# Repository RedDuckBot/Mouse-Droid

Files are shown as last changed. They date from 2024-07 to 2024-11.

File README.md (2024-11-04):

# Mouse_Droid
A differential drive mouse droid, from the Star Wars universe, that was design for entertaining people at a house party. The droid is equiped with a revolving disco ball and can make actual mouse droid sounds heard from the movies. It is manually operated using an Xbox 360 wired controller. Overall, the operations of droid involves a raspberry pi 3B+, utilizing Ubuntu Server 22.04, and the running software application is built on the middleware ROS2 Humble. Majority of the parts are 3D printed and the droid consists of many other basic electronic components. Using a PID controller the droid is able to do a 180 degree or complete rotation.    

<p align='center'>
    
</p>
<p align='center'>
    
</p>

## 🗃️ Package Overview
- [`droid_server_commands`](./droid_setup/ros2_ws/src/droid_server_commands/) : Contains action server nodes for handling controller input
- [`droid_controller`](./remote_setup/ros2_ws/src/droid_controller/) : Contains action client node that casts the inputs for the Xbox 360 controller
- [`droid_interfaces`](./remote_setup/ros2_ws/src/droid_interfaces/) : Contains the ROS2 actions and messages used in this project representing the data for Xbox 360 controller

## 🧰 Hardware

<p align='center'>
    
</p>

| | Electronic Components |
| --| --|
|1| Raspberry Pi 3B+ |
|2| Lexar 128 GB SD Card |
|3| Sound Board DY-HV20T |
|4| 4 Ohm 5W Audio Speaker |
|5| Motor Controller L298N  |
|6| [4 x DC-12V-200RPM Motors](https://ca.robotshop.com/products/lynxmotion-12vdc-200rpm-078kg-cm-ghm-16-w-rear-shaft?variant=42411388829847)|
|7| DC 5V Stepper Motor 28BYJ-48 |
|8| ULN2003 Step Driver Board |
|9| [12mm (Outside Diameter) Slip Ring](https://www.amazon.ca/dp/B07H2SRMXP?psc=1&ref=ppx_yo2ov_dt_b_product_details) |
|10| [Mini USB Disco Ball with 62mm Diameter](https://www.amazon.ca/dp/B0BK6Z3LYH?ref=ppx_yo2ov_dt_b_product_details&th=1) |
|11| 12V, 3800mAh LIPO Battery |
|12| 5V, 26000mAh Battery Bank |

### 3D Printed Parts

The parts for the droids body were taken from a maker on Thingiverse, [Null_Hypothesis](https://www.thingiverse.com/null_hypothesis/designs). Here's the link to his project https://www.thingiverse.com/thing:4229599.
From his project only the following parts are needed, given that the design needed to be hacked to work for a diff drive droid:
- 2 x Chassis_Rear_V4.stl
- Top_FrontV4.stl
- Top_RearV4.stl
- Top_rightV4.stl
- Top_RoofV4.stl
- TopLeftV4.stl
- 2 x Mouse_Droid_Side_Circuit_Board_Rescaled.stl   
- 2 x MSE_base 6to10.stl
- 2 x MSE_Lower_Portion6to10.stl
- 2 x MSE_Upper_Portion 6to10.stl
- 4 x Front_Tire.stl

The parts mentioned above and custom parts made for this project are in the 3D_print_files directory.
Portions of the chassis where the wheels go were cut out for placing the custom motor mounts, and a 64mm hole was cut out from the droid's roof for dico ball placement. Moreover, the custom disco platforms, made to hold electronic and mechanical components for operating it, are suspended bellow the droid's roof using hex brass standoffs. [`Images`](./docs/images/) were taken to show assembeled components.  

## Circuit Diagrams 
### Disco Ball Circuit
<p align="center">
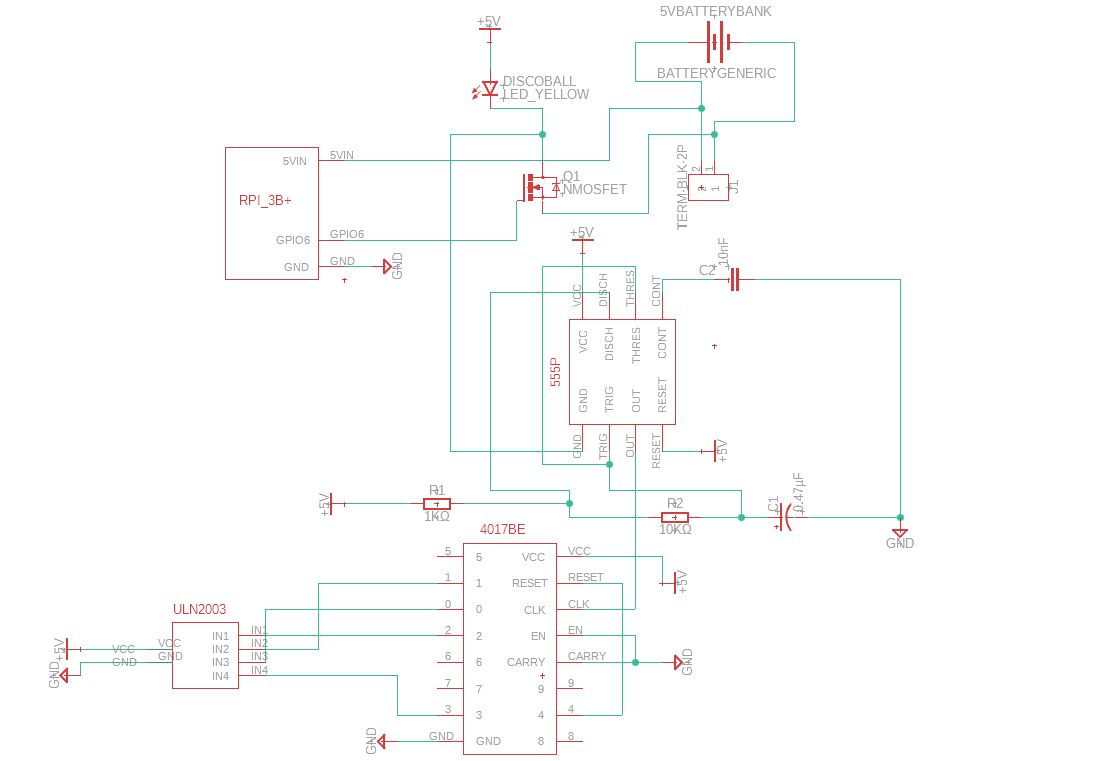
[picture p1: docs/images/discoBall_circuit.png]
Disco Ball Circuit
  
</p>
Rotational control for the disco ball was done using a custom circuit, as shown above, involving a 555 timer, 4017 Decade counter, few resistors, capacitors, and an N-mosfet. This circuit generates steps for the stepper motor and was controlled off a pin from the Raspberry Pi that connected to the mosfet; operation can easily be achieved by directly connecting the Pi's pins to the ULN2003 Step board, instead of making and using the custom circuit.
Note: since the disco ball uses a USB connection a portion of the metal connector was cut out to expose the Vin and GND pins, which were soldered to the spin wires of the slip ring with the out wires connecting to the mosfet.

### Sound Board, Motor Controller, and IMU Circuit
<p align="center">
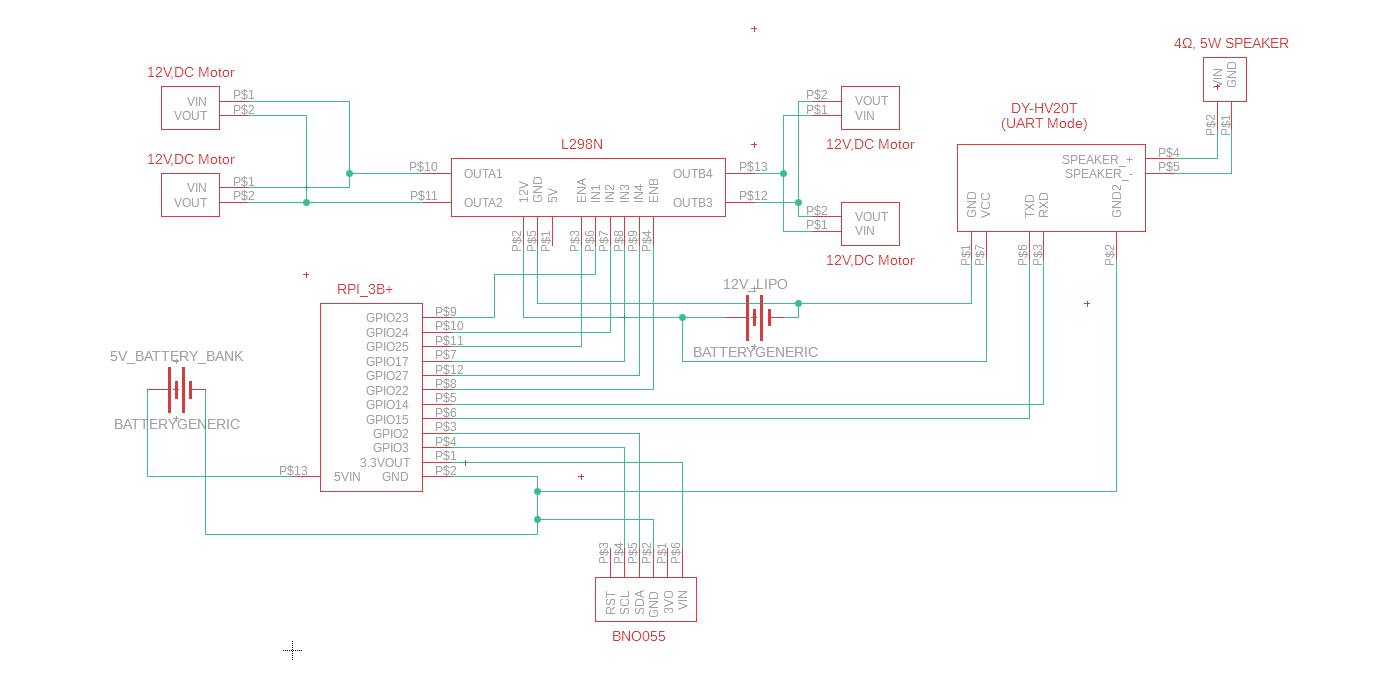
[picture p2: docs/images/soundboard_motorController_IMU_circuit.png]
Sound Board, Motor Controller, and IMU Circuit
  
</p>
In the above diagram, two power sources are utilized: 3s LIPO battery for powering the sound board and motors, and 5V battery bank for the Raspberry PI and disco circuit.

## Setup for operating the Droid 

The remote computer for controlling the droid does not need to install ROS2 Humble since in this setup a Docker container is utilized (for easy setup), but on the Raspberry PI this needs to be installed.
Copy the directory [`remote_setup`](./remote_setup/) onto the remote machine, and [`droid_setup`](./droid_setup/) onto the Raspberry PI.

### Remote Setup
For network communication, this project utilizes Eclipse Cyclone DDS, so before building and running the Docker container, add both the PI's and remote computer's IP addresses to the [`cyclon file`](./remote_setup/cyclonedds.xml). Moreover, this document provides comments for where to place these addresses. 

After modifying the cyclon file, build & run the container:

```
Scripts/build.bash
```
Next, run the container but make sure the Xbox 360 controller is connected.

```
Scripts/run.bash
```

Finally, before running the controller node, the ROS2 packages for this setup need to be compiled and installed.

```
cd ws/
colcon build
source install/setup.bash
ros2 run droid_controller controller
```
Expect similar output, after running the controller node: [INFO] [1720638165.505265926] [controller]: Xbox controller node initialized.

### Droid Setup
Make sure the library [pigpio](https://abyz.me.uk/rpi/pigpio/) is installed on the Raspberry PI.
Given permission issues encountered when trying to run the droid server node on the PI, the work around solution is running this node while logged in as the root user. 

Before compiling and installing the ROS2 packages for this setup, run the following commands:
```
source /opt/ros/humble/setup.bash
export RMW_IMPLEMENTATION=rmw_cyclonedds_cpp
export ROS_DOMAIN_ID=0
export CYCLONEDDS_URI= ./droid_setup/cyclonedds.xml #Enter the full location of the cyclon DDS file
```

Then, as done in the remote setup, add the PI's and remote computer's IP addresses to the cyclon file.
Next, while in the the directory ./droid_setup/ros2_ws, compile the droids ROS2 packages:

```
colcon build
source install/setup.bash
```

Finally, run the droid server node which takes commands from the controller node:
```
ros2 run droid_server_commands droid_server
```

Expect similar output, after running this node: 
```
[INFO] [1720639837.026257729] [Droid_Server]: IMU Module Ready
[INFO] [1720639837.164474318] [Droid_Server]: Sound Module Ready
[INFO] [1720639837.164727443] [Droid_Server]: Droid servers started
```

### Xbox 360 Controller Commands
- Left Joy-stick ---> operates left side motors
- Right Joy-stick ---> operates right side motors
- Back button ---> Droid performs an automatic 180 deg rotation
- Mode button (between back & start buttons) ---> Droid performs an automatic 360 deg rotation
- X, Y, B, A buttons ---> Perform droid sounds
- Start button ---> toggles disco ball on and off

The droid sounds are in [`resources`](./resources/) and can be installed to an SD for the sound board. 

## Acknowledgements
- [IMU Module](https://github.com/CVino/RPi_BNO055)
- [Motor Wrapper](https://github.com/buildrobotsbetter/rpi4b_gpio-example)
- [Sound Module](https://github.com/SnijderC/dyplayer)

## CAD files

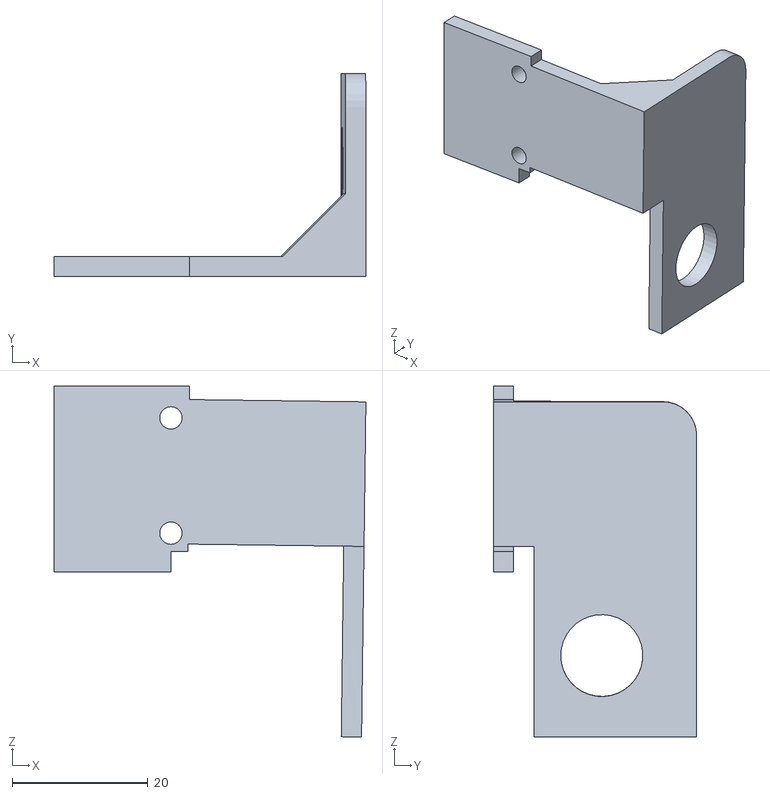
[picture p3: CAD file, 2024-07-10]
3D_print_files/custom_parts/left_side_motor_bracket.stl
46.0 x 30.0 x 51.8

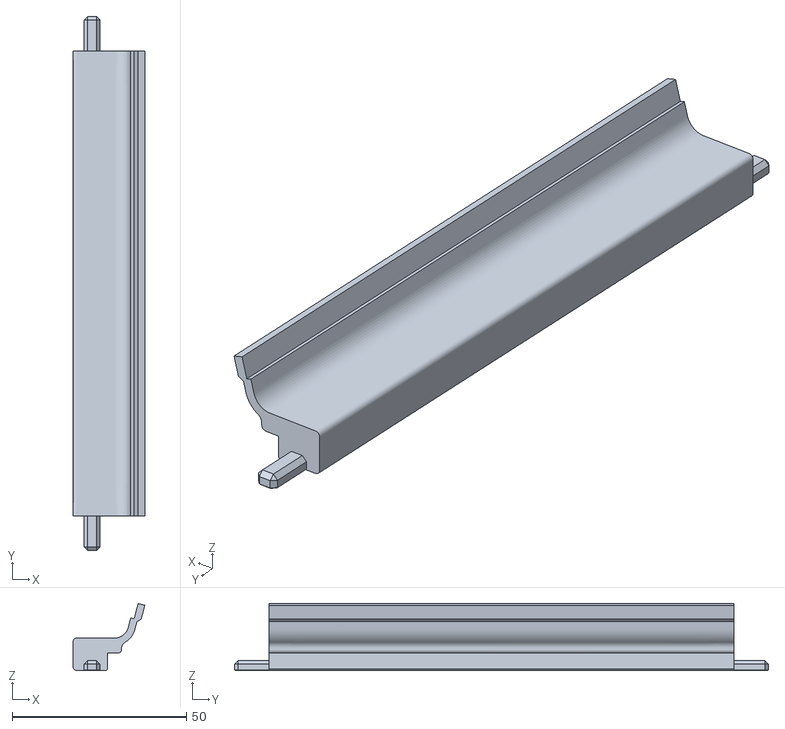
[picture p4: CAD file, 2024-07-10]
3D_print_files/original_parts/TopLeftV4.stl
20.6 x 153.0 x 19.2

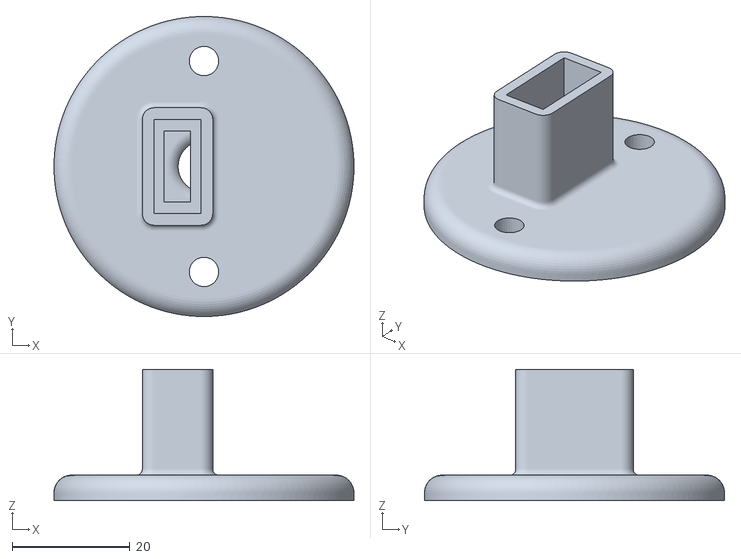
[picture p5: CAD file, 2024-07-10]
3D_print_files/custom_parts/disco_holder.stl
51.1 x 51.1 x 22.4

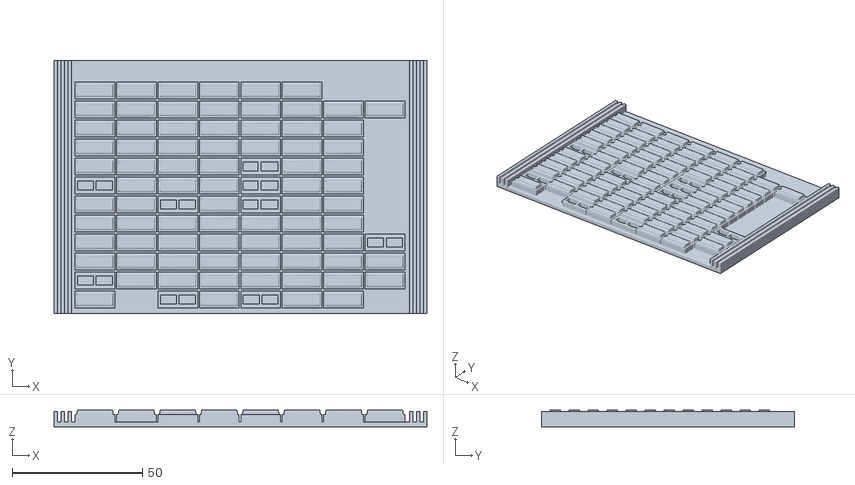
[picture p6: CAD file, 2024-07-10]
3D_print_files/original_parts/Mouse_Droid_Side_Circuit_Board_Rescaled.stl
143.0 x 97.2 x 6.37

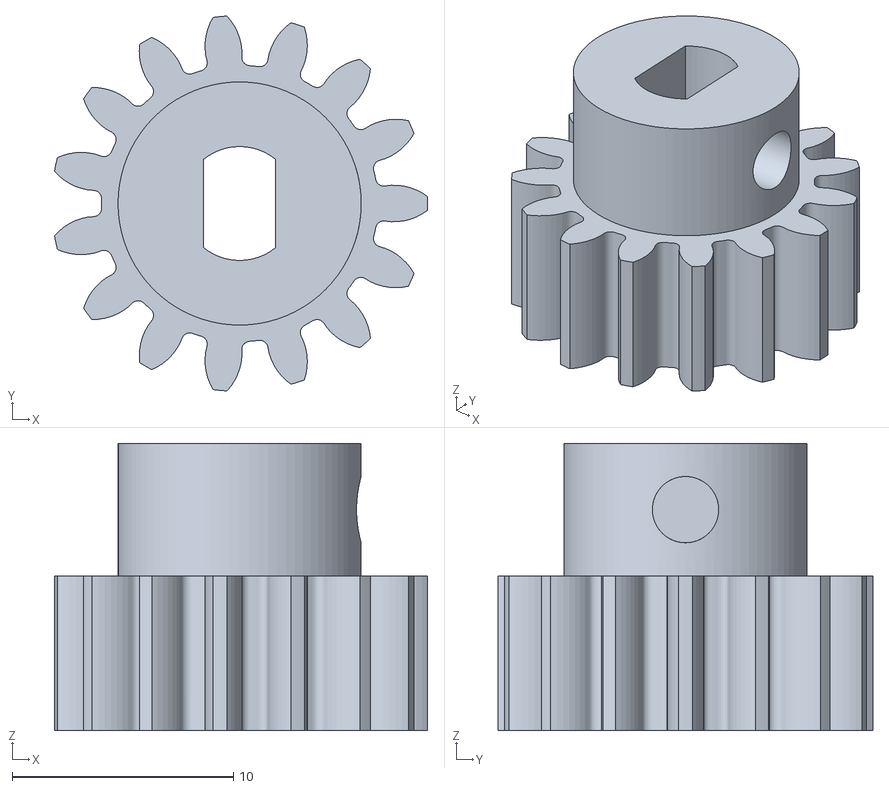
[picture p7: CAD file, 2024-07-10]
3D_print_files/custom_parts/stepper_driven_gear.stl
16.9 x 17.0 x 13.0

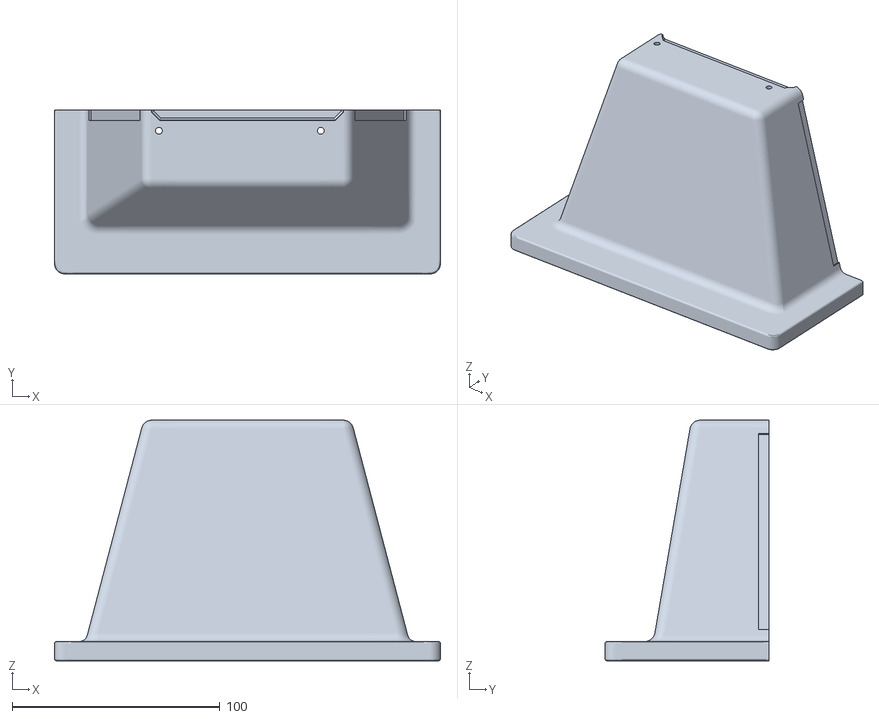
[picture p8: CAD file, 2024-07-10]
3D_print_files/original_parts/Top_RearV4.stl
186.0 x 79.0 x 115.9

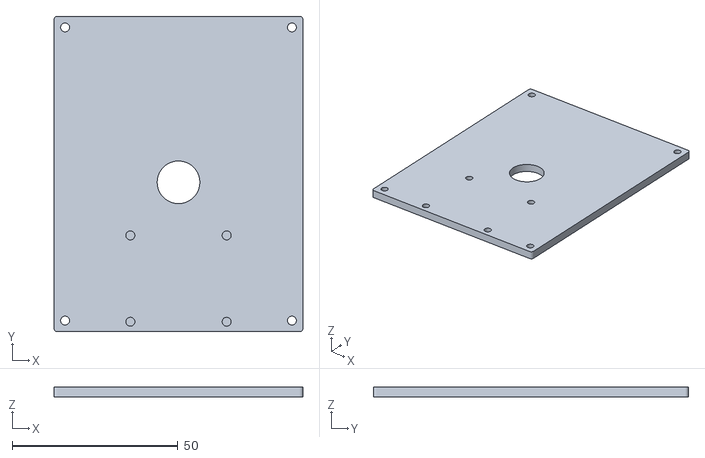
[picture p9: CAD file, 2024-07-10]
3D_print_files/custom_parts/bottom_disco_platform.stl
75.0 x 95.0 x 3.00

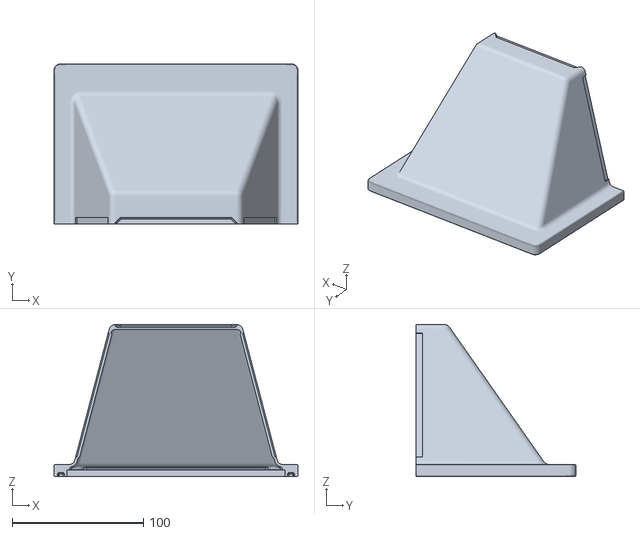
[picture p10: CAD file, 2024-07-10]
3D_print_files/original_parts/Top_FrontV4.stl
186.0 x 122.1 x 115.9

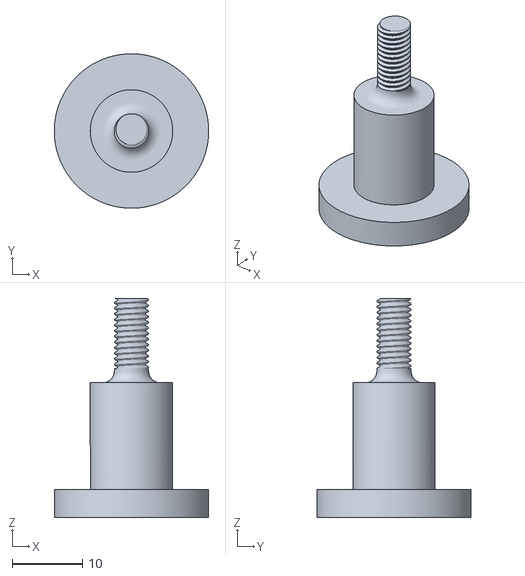
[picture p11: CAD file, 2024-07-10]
3D_print_files/custom_parts/wheel_and_hub_connector.stl
22.0 x 22.0 x 31.2

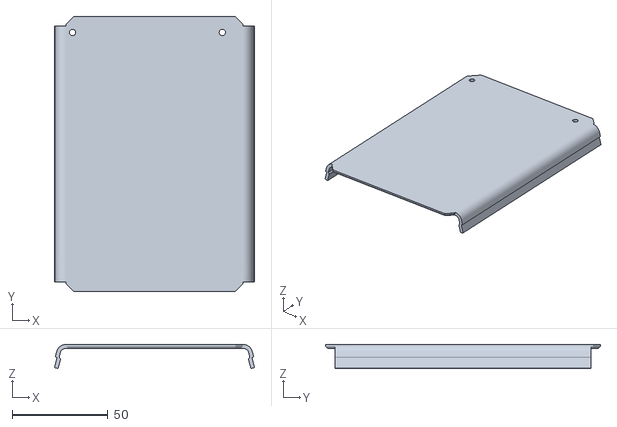
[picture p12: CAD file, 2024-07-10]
3D_print_files/original_parts/Top_RoofV4.stl
104.2 x 143.2 x 12.5

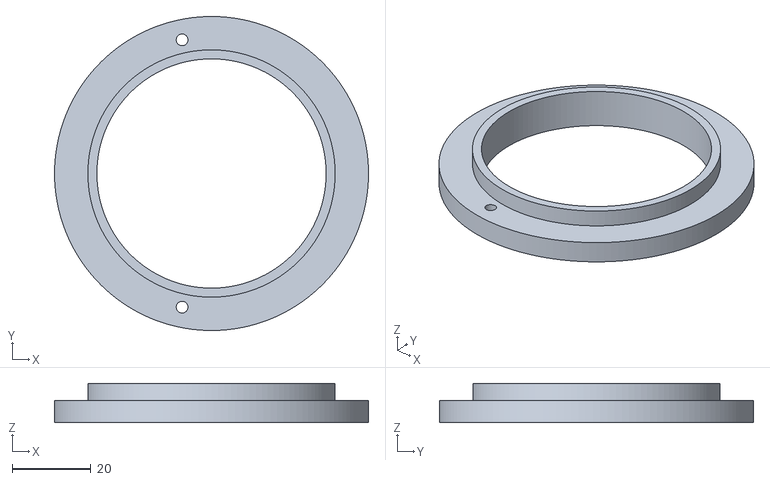
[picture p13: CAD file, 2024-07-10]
3D_print_files/custom_parts/bottom_disco_dome_cover.stl
80.0 x 80.0 x 10.0

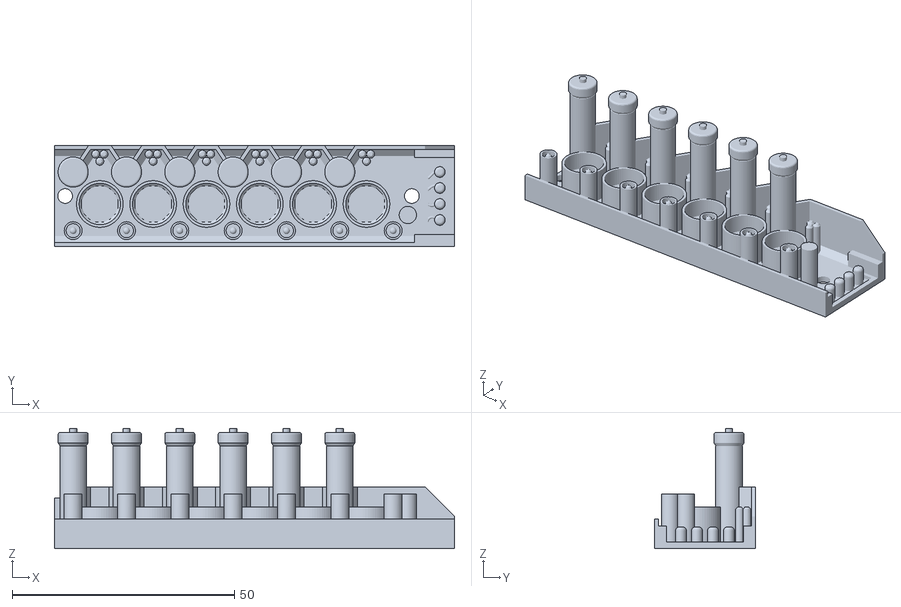
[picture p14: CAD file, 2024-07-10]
3D_print_files/original_parts/MSE_Upper_Portion_6to10.stl
90.0 x 22.8 x 27.0

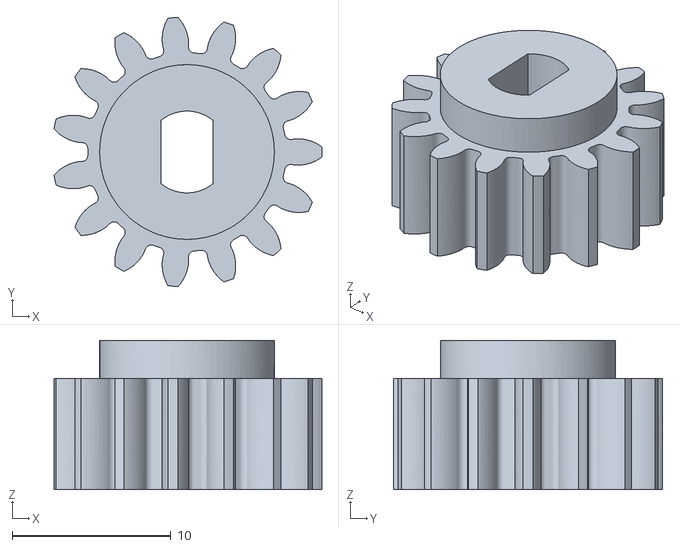
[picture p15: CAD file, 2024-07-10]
3D_print_files/custom_parts/stepper_drive_gear.stl
16.9 x 17.0 x 9.40

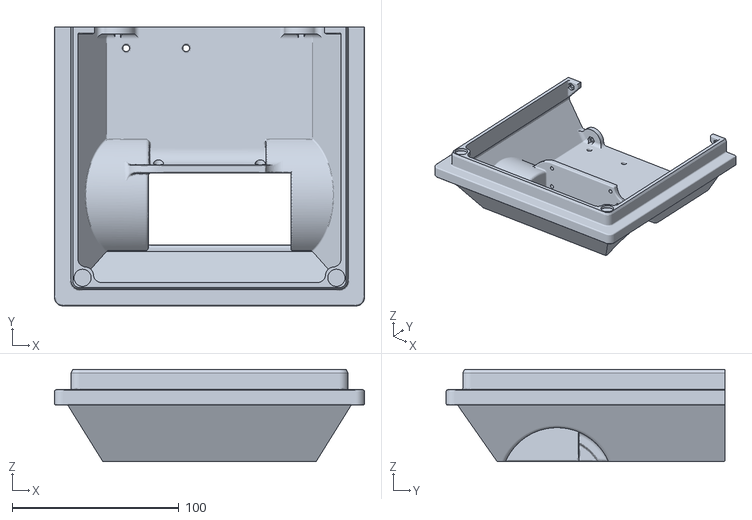
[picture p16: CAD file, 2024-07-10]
3D_print_files/original_parts/Chassis_Rear_V4.stl
186.0 x 167.2 x 55.3

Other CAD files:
3D_print_files/original_parts/Top_rightV4.stl
3D_print_files/custom_parts/right_side_motor_bracket.stl
3D_print_files/custom_parts/top_disco_dome_cover.stl
3D_print_files/original_parts/MSE_base_6to10.stl
3D_print_files/custom_parts/top_disco_platform.stl
3D_print_files/original_parts/Front_Tire.stl
3D_print_files/original_parts/MSE_Lower_Portion6to10.stl

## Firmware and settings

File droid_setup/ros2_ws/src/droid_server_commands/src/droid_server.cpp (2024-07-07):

#include "rclcpp/rclcpp.hpp"
#include "rclcpp_action/rclcpp_action.hpp"
#include "droid_interfaces/action/drive.hpp"
#include "droid_interfaces/msg/xbox_controller.hpp"
#include "sound_module/SoundPlayer.hpp"
#include "libgpio/MotorDriver.hpp"
#include "libgpio/DigitalOutput.hpp"
#include <chrono>
#include <cstdlib>
#include <unistd.h>
#include <pigpio.h>
#include "imu_module/RPi_Sensor.h"
#include "imu_module/RPi_BNO055.h"
#include "imu_module/utility/imumaths.h"
#include "controller_PID/PID.hpp"

using Drive = droid_interfaces::action::Drive;
using Xcontroller = droid_interfaces::msg::XboxController;
using DroidGoalHandle = rclcpp_action::ServerGoalHandle<Drive>;
using namespace std::placeholders;
using DY::Player;
using Controllers::PID;
using namespace libgpio;


class DroidServerNode: public rclcpp:: Node
{
    public:
        DroidServerNode(char * sound_port, 
        unsigned int in1_pin, unsigned int in2_pin, unsigned int enA_pin,
        unsigned int in3_pin, unsigned int in4_pin, unsigned int enB_pin,
        uint32_t gpio_disco_num): 
            Node("Droid_Server"), player_(sound_port), 
            leftMotors_(in3_pin,in4_pin,enB_pin),
            rightMotors_(in1_pin,in2_pin,enA_pin),
            discoPin_(gpio_disco_num)
        {
            int soundModuleReady;

            //Setup IMU sensor
            bno_ = Adafruit_BNO055();
            bno_._HandleBNO=i2cOpen(bno_._i2cChannel,BNO055_ADDRESS_A,0);
            if(!bno_.begin())
            {
                RCLCPP_INFO(this->get_logger(),
                    "No BNO055 detected ... Check your wiring or I2C ADDR!");
            }
            else
            {
                RCLCPP_INFO(this->get_logger(), "IMU Module Ready");
                bno_.setExtCrystalUse(true);
            }

            //Set disco pin
            discoPin_.setOutput(false);

            //Setup threading groups
            cb_group_1_ = this->create_callback_group(rclcpp::
                CallbackGroupType::Reentrant); //Joy-stick group
            cb_group_2_ = this->create_callback_group(rclcpp::
                CallbackGroupType::MutuallyExclusive); //Button group

            //Setup action servers
            //_1, _2 <--- refers to # of arguments used in goal_callback
            droid_server_buttons_ = rclcpp_action::create_server<Drive>(
                this,
                "droid_buttons",
                std::bind(&DroidServerNode::goal_callback_buttons,this, _1, _2), 
                std::bind(&DroidServerNode::cancel_callback_buttons, this, _1),
                std::bind(&DroidServerNode::handle_accepted_callback_buttons, 
                    this, _1),
                rcl_action_server_get_default_options(),
                cb_group_1_
            );
            droid_server_joy_ = rclcpp_action::create_server<Drive>(
                this,
                "droid_motors",
                std::bind(&DroidServerNode::goal_callback_joys,this, _1, _2), 
                std::bind(&DroidServerNode::cancel_callback_joys, this, _1),
                std::bind(&DroidServerNode::handle_accepted_callback_joys, 
                    this, _1),
                rcl_action_server_get_default_options(),
                cb_group_2_
            );

            //Setup motors
            int frequency = 800; // 800 Hz
            gpioSetPWMfrequency(enA_pin, frequency);
            gpioSetPWMfrequency(enB_pin, frequency);
            leftMotors_.setDirection(MotorDirection::FORWARD);
            leftMotors_.setEffort_percent(0.0);
            rightMotors_.setDirection(MotorDirection::FORWARD);
            rightMotors_.setEffort_percent(0.0);

            //Setup sound board
            soundModuleReady = player_.begin();
            player_.setVolume(30);
            player_.setCycleMode(DY::PlayMode::OneOff);
            if (soundModuleReady == 0) 
            {
                RCLCPP_INFO(this->get_logger(), "Sound Module Ready");
                UART_filestream_number = player_.UART_filestream;
            }
            else 
            {
                RCLCPP_INFO(this->get_logger(), "Sound Module not Ready");
            }

            RCLCPP_INFO(this->get_logger(), "Droid servers started");
        }

        ~DroidServerNode()
        {
            if (UART_filestream_number != -1)
            {
                close(UART_filestream_number);
            }

            RCLCPP_INFO(this->get_logger(), "Cleaned up resources"); 
        }

    private:
        int UART_filestream_number = -1; //Used to close UART connection to sound module
        Player player_; //Sound player
        Adafruit_BNO055 bno_; //IMU
        MotorDriver leftMotors_, rightMotors_;
        DigitalOutput discoPin_;

        bool rotate_button_active = false;
        //PID controller for 180 degree rotation
        PID pid_180_ = PID(100.0 / 180.0, 0.0, 0.0); 

        rclcpp_action::Server<Drive>::SharedPtr droid_server_buttons_;
        rclcpp_action::Server<Drive>::SharedPtr droid_server_joy_;
        rclcpp::CallbackGroup::SharedPtr cb_group_1_;
        rclcpp::CallbackGroup::SharedPtr cb_group_2_;

        std::shared_ptr<DroidGoalHandle> goal_handle_joy_;
        std::shared_ptr<DroidGoalHandle> goal_handle_button_;
        std::mutex mutex_joy_;
        std::mutex mutex_button_;

        rclcpp_action::GoalUUID prempt_rotate_goal_id_;

        rclcpp_action::GoalResponse goal_callback_joys(
            const rclcpp_action::GoalUUID &uuid, 
            std::shared_ptr<const Drive::Goal> goal)
        {
            {
                //Policy: refuse new joy stick goal if one is active
                //Or if buttons for rotating is active
                std::lock_guard<std::mutex> lock(mutex_joy_);
                if (goal_handle_joy_)
                {
                    if (goal_handle_joy_ -> is_active())
                    {
                        RCLCPP_INFO(this->get_logger(), 
        "[Joy-Server]: A joy-stick command is active; reject new joy goal.");
                        return rclcpp_action::GoalResponse::REJECT;
                    }

                    if (rotate_button_active)
                    {
                        RCLCPP_INFO(this->get_logger(),
            "[Joy-Server]: joy goal rejected since rotate button is active.");
                        return rclcpp_action::GoalResponse::REJECT;
                    }
                }
            }

            (void) uuid;
            (void) goal;
            return rclcpp_action::GoalResponse::ACCEPT_AND_EXECUTE;
        }

        rclcpp_action::GoalResponse goal_callback_buttons(
            const rclcpp_action::GoalUUID &uuid, 
            std::shared_ptr<const Drive::Goal> goal)
        {
            (void) uuid;
            (void) goal;
            return rclcpp_action::GoalResponse::ACCEPT_AND_EXECUTE;
        }

        rclcpp_action::CancelResponse cancel_callback_buttons(
            const std::shared_ptr<DroidGoalHandle> goal_handle)
        {
            (void) goal_handle;
            return rclcpp_action::CancelResponse::ACCEPT;
        }
        
        rclcpp_action::CancelResponse cancel_callback_joys(
            const std::shared_ptr<DroidGoalHandle> goal_handle)
        {
            (void) goal_handle;
            return rclcpp_action::CancelResponse::ACCEPT;
        }

        void handle_accepted_callback_joys(
            const std::shared_ptr<DroidGoalHandle> goal_handle)
        {
            {
                std::lock_guard<std::mutex> lock(mutex_joy_);
                this-> goal_handle_joy_ = goal_handle;
            }

            auto goal = goal_handle->get_goal();

            if (goal->is_joy_command) 
            {
                execute_joy_goal(goal_handle);
            }
            send_goal_result(goal_handle);
        }
        
        void handle_accepted_callback_buttons(
            const std::shared_ptr<DroidGoalHandle> goal_handle)
        {
            auto goal = goal_handle->get_goal();

            if (goal->is_sound_command) 
            {
                execute_sound_goal(goal_handle);
            }

            if (goal->is_disco_command)
            {
                execute_disco_goal(goal_handle);
            }

            if (goal->is_rotate_command) 
            {
                if (rotate_button_active)
                {

                }
                else 
                {
                    {
                        std::lock_guard<std::mutex> lock(mutex_button_);
                        goal_handle_button_ = goal_handle;
                    }
                    rotate_button_active = true;
                    execute_rotate_goal(goal_handle);
                    rotate_button_active = false;

                }
            }
        }

        void execute_rotate_goal(const std::shared_ptr<DroidGoalHandle> 
            goal_handle)
        {
            auto rotate_goal = goal_handle -> get_goal();
            Xcontroller controller = rotate_goal -> controller;

            int heading_goal;
            imu::Vector<3> euler = 
                bno_.getVector(Adafruit_BNO055::VECTOR_EULER);

           if (controller.back == true) //button for 180 degree rotation
           {
                heading_goal = ((int) (euler.x() + 180.0)) % 360;
                pid_180_.set_heading_goal(heading_goal);
                handle_rotation(heading_goal, pid_180_);
           }
           else //Handle center button press (rotate 360 degrees)
        {
                heading_goal = ((int) (euler.x() + 180.0)) % 360;
                pid_180_.set_heading_goal(heading_goal);
                handle_rotation(heading_goal, pid_180_);

                sleep(0.5);
                imu::Vector<3> euler = 
                    bno_.getVector(Adafruit_BNO055::VECTOR_EULER);

                heading_goal = ((int) (euler.x() + 180.0)) % 360;
                pid_180_.set_heading_goal(heading_goal);
                handle_rotation(heading_goal, pid_180_);
           }

            send_goal_result(goal_handle);

        }

        void handle_rotation(double heading_goal, PID pid)
        {
            double tolerated_error = 5.0; //Degrees
            double current_heading;
            double motors_adjustment; 
            imu::Vector<3> euler;  

            leftMotors_.setEffort_percent(0.0);
            rightMotors_.setEffort_percent(0.0);

            sleep(0.5);

            std::cout << "\nHeading Goal: " << heading_goal << std::endl;

            //Only move clockwise
            leftMotors_.setDirection(MotorDirection::FORWARD);
            rightMotors_.setDirection(MotorDirection::BACKWARD);

            while (true)
            {
                euler = bno_.getVector(Adafruit_BNO055::VECTOR_EULER);
                current_heading = euler.x(); 

                motors_adjustment = pid.compute_adjustment(current_heading);
                current_heading = euler.x(); 

                if (abs(pid.get_error()) < tolerated_error )
                {
                    break;
                }

                //Constrain motor adjustment within [70,100.0]
                if (motors_adjustment > 100.0)
                {
                    motors_adjustment = 100.0;
                } else if (motors_adjustment < 70.0)
                {
                    motors_adjustment = 70.0;
                } else
                {
                    motors_adjustment = motors_adjustment;
                }

                leftMotors_.setEffort_percent(motors_adjustment);
                rightMotors_.setEffort_percent(motors_adjustment);

                sleep(0.5);
            }
            
            std::cout << "Final Heading: " << current_heading << std::endl;
            leftMotors_.setEffort_percent(0.0);
            rightMotors_.setEffort_percent(0.0);

        }

        void execute_disco_goal(const std::shared_ptr<DroidGoalHandle>
            goal_handle)
        {
            if (discoPin_.getState() == true)
            {
                discoPin_.setOutput(false);
            } 
            else
            {
                discoPin_.setOutput(true);
            }
            send_goal_result(goal_handle);
        }

        void execute_sound_goal(const std::shared_ptr<DroidGoalHandle> 
            goal_handle)
        {
            auto sound_goal = goal_handle -> get_goal();

            handle_sound_command(sound_goal->controller);
            send_goal_result(goal_handle);

        }

        void send_goal_result(const std::shared_ptr<DroidGoalHandle> goal_handle)
        {
            auto result = std::make_shared<Drive::Result>();
            result->reached_command = "Success";
            goal_handle->succeed(result);
        }

        void handle_sound_command(Xcontroller controller)
        {
            
           if (controller.x) 
           {
                player_.playSpecifiedDevicePath(DY::Device::Sd, "/chat2.wav");
           }
           else if (controller.y)
           {
                player_.playSpecifiedDevicePath(DY::Device::Sd, "/chirp2.wav");
           } 
           else if (controller.b)
           {
                player_.playSpecifiedDevicePath(DY::Device::Sd, "/chirp1.wav");
           } 
           else //Handle button press a
           {
                player_.playSpecifiedDevicePath(DY::Device::Sd, "/gen3.wav");
           }
        }

        void execute_joy_goal(const std::shared_ptr<DroidGoalHandle> 
            goal_handle)
        {
            auto joy_goal = goal_handle -> get_goal();
            Xcontroller controller = joy_goal -> controller;
            
            MotorDirection left_joy_dir;
            MotorDirection right_joy_dir;
            double new_left_motors_effort, new_right_motors_effort;
            
            //Set left joy stick direction
            if (controller.left_joy_y < 0)
            {
                left_joy_dir = MotorDirection(MotorDirection::FORWARD);
            } 
            else 
            {
                left_joy_dir = MotorDirection(MotorDirection::BACKWARD);
            }

            //Set right joy stick direction
            if (controller.right_joy_y < 0)
            {
                right_joy_dir = MotorDirection(MotorDirection::FORWARD);
            }
            else
            {
                right_joy_dir = MotorDirection(MotorDirection::BACKWARD);
            }

            //Check for change in motor directions
            if (leftMotors_.getDirection() != left_joy_dir)
            {
                leftMotors_.setDirection(left_joy_dir);
            }
            if (rightMotors_.getDirection() != right_joy_dir)
            {
                rightMotors_.setDirection(right_joy_dir);
            }

            new_left_motors_effort = controllerInput_to_motorEffort(
                abs(controller.left_joy_y));
            new_right_motors_effort = controllerInput_to_motorEffort(
                abs(controller.right_joy_y));

            leftMotors_.setEffort_percent(new_left_motors_effort);
            rightMotors_.setEffort_percent(new_right_motors_effort);

        }

        double controllerInput_to_motorEffort(double joy_stick_input) 
        {
            return joy_stick_input * 100;
        }
};

int main(int argc, char ** argv)
{
     //Right motors is controlled using to GPIO23 (pin 16), GPIO24 (pin 18), 
     //and GPIO25 (pin 22)
    static unsigned int IN1_PIN = 23; 
    static unsigned int IN2_PIN = 24; 
    static unsigned int ENA_PIN = 25;

    //Left motors is controlled using to GPIO17 (pin 11), GPIO27 (pin 13), and 
    //GPIO22 (pin 15)
    static unsigned int IN3_PIN = 17; 
    static unsigned int IN4_PIN = 27; 
    static unsigned int ENB_PIN = 22;

    //Disco pin GPIO5
    uint32_t disco_pin = 6;

    char sound_port[] = "/dev/serial0";
    rclcpp::init(argc,argv);
    auto droid_server_node = std::make_shared<DroidServerNode>(
        sound_port,
        IN1_PIN, IN2_PIN, ENA_PIN,
        IN3_PIN, IN4_PIN, ENB_PIN,
        disco_pin);

    rclcpp::executors::MultiThreadedExecutor executor;
    executor.add_node(droid_server_node);
    executor.spin();
    rclcpp::shutdown();
    return 0;
}

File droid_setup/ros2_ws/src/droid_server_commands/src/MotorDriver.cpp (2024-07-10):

#include "libgpio/MotorDriver.hpp"

#include <stdexcept>
#include <fmt/core.h>
#include <iostream>

//File taken from repo: https://github.com/buildrobotsbetter/rpi4b_gpio-example
namespace libgpio
{

MotorDriver::MotorDriver(uint32_t input1Pin, uint32_t input2Pin, uint32_t enablePin):
    m_input1Pin(input1Pin),
    m_input2Pin(input2Pin),
    m_enablePin(enablePin),
    m_effort_percent(0.0)
{
    setDirection(MotorDirection::FORWARD);
}

MotorDriver::~MotorDriver()
{
    // Automatically stop the motor on destruction
    setEffort_percent(0.0);
}

const MotorDirection& MotorDriver::getDirection() const
{
    return m_direction;
}

void MotorDriver::setDirection(const MotorDirection& value)
{
    m_direction = value;
    switch (m_direction)
    {
        case MotorDirection::FORWARD:
        {        
            m_input1Pin.setOutput(true);
            m_input2Pin.setOutput(false);
            break;
        }

        case MotorDirection::BACKWARD:
        {        
            m_input1Pin.setOutput(false);
            m_input2Pin.setOutput(true);
            break;
        }
    }
}

double MotorDriver::getEffort_percent() const
{
    return m_effort_percent;
}

void MotorDriver::setEffort_percent(double value)
{
    if ((value < 0.0) || (value > 100.0))
    {
        throw std::runtime_error(fmt::format("Effort value {} is invalid. Valid range [0.0, 100.0]", value)); 
    }

    m_effort_percent = value;

    int duty_cycle = (int) (255 * (m_effort_percent / 100.0));
    auto result = gpioPWM(m_enablePin, duty_cycle);
    if (result == 0)
    {
        return;
    }

    switch (result)
    {       
        case PI_BAD_USER_GPIO:
        {
            throw std::runtime_error(fmt::format("{} is a bad gpio pin", m_enablePin));
        }

        case PI_BAD_DUTYCYCLE:
        {
            throw std::runtime_error(fmt::format("Bad duty cycle specified for gpio pin {}", m_enablePin));
        }

        default:
        {
            throw std::runtime_error(fmt::format("Unexpected error encountered when setting mode specified for gpio pin {} (Error = {})", m_enablePin, result));
        }
    }
}

} // namespace libgpio
